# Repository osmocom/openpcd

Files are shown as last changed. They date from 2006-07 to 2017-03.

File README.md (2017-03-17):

OpenPCD, OpenPICC and SIMtrace device firmware
==============================================

This repository contains the C-language firmware of a couple of
different USB devices that share nothing in common but the fact that
they contain and Atmel AT91SAM7S microcontroller and that Harald Welte
was involved in their development.

The OpenPCD 1.x and OpenPICC 1.x devices are pretty much obsolete these
days, so SAM7S based SIMtrace 1.x is the only relevant platform these
days.

[Osmocom](https://osmocom.org/)
[SIMtrace](https://osmocom.org/projects/simtrace) is a USB-attached
peripheral device that is primarily used to sniff the traffic between a
SIM/USIM card and a Phone or cellular modem.

Homepage
--------

The official homepage of the project is
<https://osmocom.org/projects/simtrace/wiki/>

GIT Repository
--------------

You can clone from the official openpcd.git repository using

	git clone git://git.osmocom.org/openpcd.git

There is a cgit interface at <http://git.osmocom.org/openpcd/>

Documentation
-------------

Ther homepage (see above) contains a wiki with information as well as
the SIMtrace user manual.

Mailing List
------------

Discussions related to SIMtrace are happening on the
simtrace@lists.osmocom.org mailing list, please see
<https://lists.osmocom.org/mailman/listinfo/simtrace> for subscription
options and the list archive.

Please observe the [Osmocom Mailing List
Rules](https://osmocom.org/projects/cellular-infrastructure/wiki/Mailing_List_Rules)
when posting.

Contributing
------------

Our coding standards are described at
<https://osmocom.org/projects/cellular-infrastructure/wiki/Coding_standards>

We use accept code/patch submissions via e-mail to the above-mentioned
mailing list.

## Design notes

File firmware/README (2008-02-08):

Different Targets can be built by implementing a _init_func() and _main_func()_
function in src/main_foo.c

The resulting binary main_foo.bin can be built by issuing
	make BOARD=PCD TARGET=main_foo

If you want to add debugging support (debug unit aka DBGU, RS232), add DEBUG=1

Building dfu.bin (the DFU loader binary):
	make -f Makefile.dfu BOARD=PCD

For more information, please read http://wiki.openpcd.org/wiki/Firmware

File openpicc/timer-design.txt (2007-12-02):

from analog: SSC_DATA, CARRIER (via PLL)
to analog: MOD

MOD                   on PA17 (SSC TD, out), PA23 (PWM0, out)
SSC_DATA              on PA18 (SSC RD, in),  PA27 (TIOB2, in)
FRAME                 on PA20 (SSC RF, in)

CARRIER          (T5) on PA28 (TCLK1, in)
CARRIER_DIV_HELP (T3) on PA0  (TIOA0, out),  PA29 (TCLK2, in)
(TF)                  on PA26 (TIOA2, out),  PA15 (SSC TF, in)

SSC_CLOCK        (T4) on PA1  (TIOB0, out),  PA19 (SSC RK, in)

MOD: pure output, to modulation circuitry
	* either fed from SSC transmitter
	* or fed from PWM
SSC_DATA: pure input, from demulation circuitry
	* goes to SSC receiver
	* goes to tc_fdt as external event (TIOB2)
FRAME: set on any edge in SSC_DATA, reset by SSC_DATA_CONTROL (out)
	* goes to SSC receiver as frame signal

CARRIER: pure input, from PLL
	* goes to tc_cdiv and tc_fdt as XC1 (TCLK1)
CARRIER_DIV_HELP: internal signal, does ???
	* comes from tc_cdiv (TIOA0)
	* goes to tc_cdiv as XC2 (TCLK2)
TF: internal signal, transmission start
	* comes from tc_fdt (TIOA2)
	* goes to SSC transmitter as frame signal

SSC_CLOCK: internal signal, transceiver clock
	* comes from tc_cdiv (TIOB0)
	* goes to SSC transmitter and receiver as clock signal

tc_cdiv: XC1=TCLK1 (in), TIOB0 (out), TIOA0 (out), XC2=TCLK2 (in)
	TC0 enabled
	XC1 = TCLK1, XC2 = TCLK2
	TC0: Clock from XC1, Wave mode, WAVSEL=2 (up auto)
		TIOA0: RA compare = set, RC compare = clear, swtrg = clear
		TIOB0: eevent = set, RB compare = clear, swtrg = clear
		eevent: XC2, external trigger on rising edge
		RA = 1, RB = 1 + divider/2, RC = divider
	
	i.o.w: when CV = 0 (either through swtrg or through RC compare) then TIOA0 and TIOB0 are clear
		TIOA0 is set on RA compare (at CV=1+phase), is connected to XC2 (through TCLK2) and therefore triggers the external event which sets TIOB0
		TIOB0 is cleared at RB compare (at CV=1+divider/2+phase)
	that means: Compare A sets TIOB and Compare B clears TIOB, Compare C is fixed at the divisor value, Compare A and B are divisor/2 apart, yielding an exact 50% duty cycle with a variable phase shift (offset from CV=0)
	this trick is necessary because TIO{A,B} can't be directly affected by Compare {B,A}, so when using only one TIO you can either get a fixed duty cycle with zero offset compared to CV=0, or a variable offset yielding a variable duty cycle

tc_fdt: TIOA2 (out), TIOB2 (in), XC1=TCLK1 (in)
	TC2 enabled
	TC2: Clock from XC1, Wave mode, WAVSEL=0 (up)
		TIOA2: RA compare = set, RC compare = clear, eevent = clear
		TIOB2: eevent = nothing, RB compare = nothing
		eevent: TIOB2, external trigger on falling edge, clock started and enabled on external trigger
		clock stopped on RC compare
		RC = 0xffff, RB = frame_end_set, RA = fdt_set

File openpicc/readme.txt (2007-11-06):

OpenBeaconUSB firmware source code tree v0.1
--------------------------------------------

Copyright 2007 Milosch Meriac <milosch@openbeacon.de>
based on http://www.freertos.org/ embedded operating system

Visit http://www.openbeacon.org/ and http://wiki.openbeacon.org/ for further
informations.

All supplied code is licensed under GNU General Public License Version 2,
June 1991. See "license.txt" file for license informations. Alternative
license types are available for the "/application"-tree on request. Please
contact milosch@openbeacon.de on license issues.

The contained firmware source code is verified to compile flawless by using
GCC version 4.0.2 configured as ARM cross compiler.

The USB device creates a virtual serial COM port - you can access it by using
115200 baud, 8 data bit, no parity and one stop bit. Under Linux just plug it
into your computer - a /dev/ttyACM? device will appear automagically.

We personally prefer the "cu" command line tool from uucp-Package to access
the created serial port easily under Linux based operating systems.

For Microsoft Windows you have to use the supplied .inf-file from the
"win32driver" directory - you can verify the assigned COM port by using the
control panel.

Use the contained "at91flash"-tool to udpate to contained firmware. The
supplied script depends on our modified sam7 tool:
http://www.openpcd.org/dl/sam7utils-0.1.0-bm.tar.bz2

Enjoy !

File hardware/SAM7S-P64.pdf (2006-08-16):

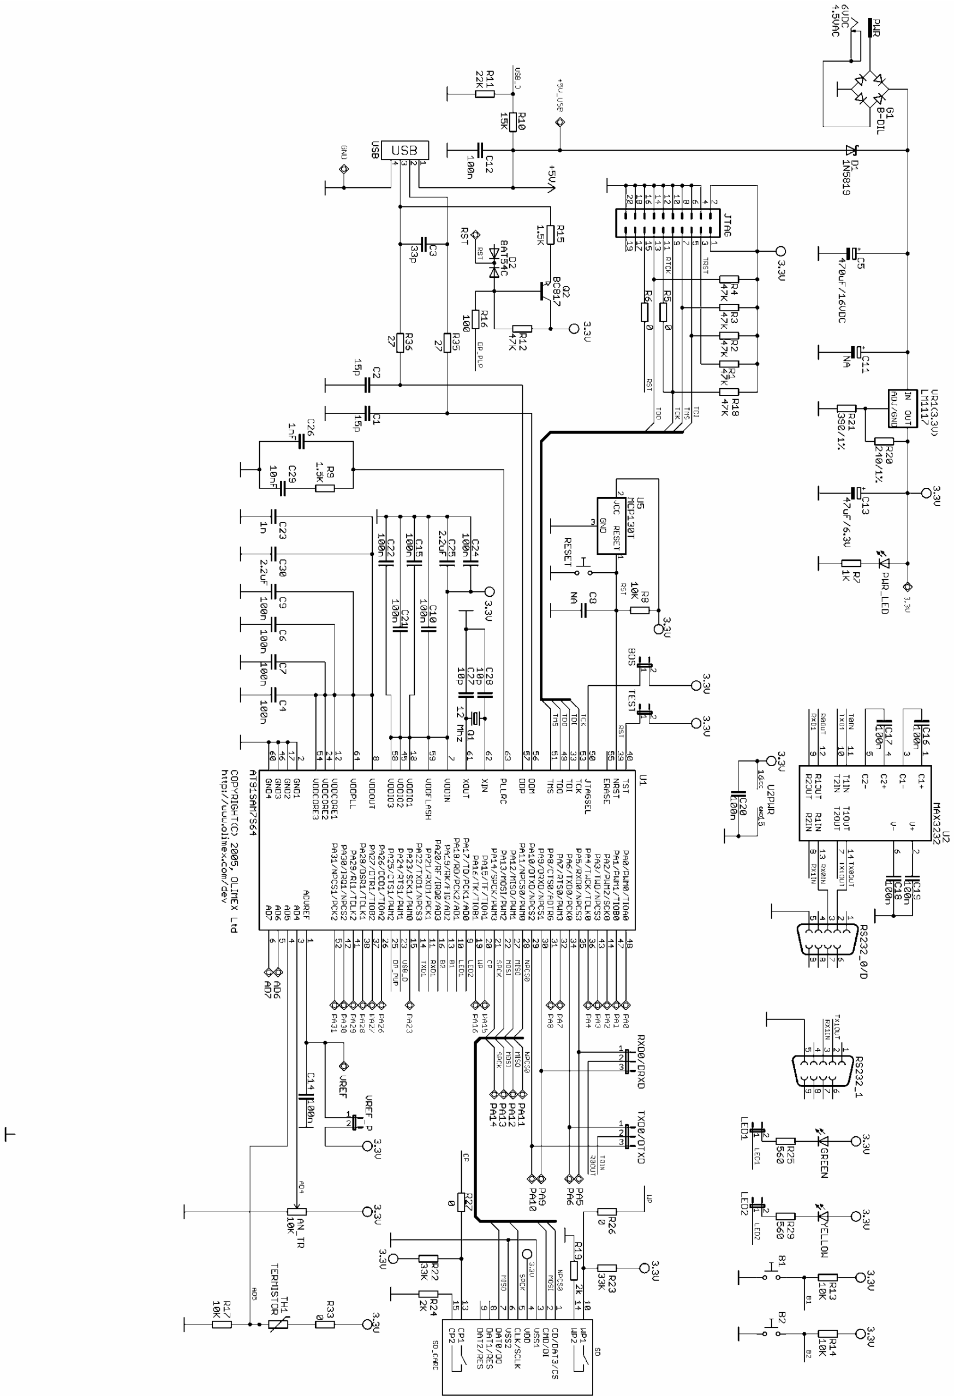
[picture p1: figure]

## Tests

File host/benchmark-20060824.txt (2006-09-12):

laforge@rama%pts/8 (1:27) kommerz/bitmanufaktur/openpcd/opcd_test > for f in 1 2 4 8 16 32 64 128 255; do ./opcd_test -u $f; done 
opcd_test - OpenPCD Test and Debug Program
(C) 2006 by Harald Welte <laforge@gnumonks.org>

starting DATA IN performance test (1 frames of 64 bytes)
TX: (4):  f1 00 ff 01
255 transfers (total 16320 bytes) in 508 miliseconds => 32125 bytes/sec
opcd_test - OpenPCD Test and Debug Program
(C) 2006 by Harald Welte <laforge@gnumonks.org>

starting DATA IN performance test (2 frames of 64 bytes)
TX: (4):  f1 00 ff 02
255 transfers (total 32640 bytes) in 510 miliseconds => 64000 bytes/sec
opcd_test - OpenPCD Test and Debug Program
(C) 2006 by Harald Welte <laforge@gnumonks.org>

starting DATA IN performance test (4 frames of 64 bytes)
TX: (4):  f1 00 ff 04
255 transfers (total 65280 bytes) in 508 miliseconds => 128503 bytes/sec
opcd_test - OpenPCD Test and Debug Program
(C) 2006 by Harald Welte <laforge@gnumonks.org>

starting DATA IN performance test (8 frames of 64 bytes)
TX: (4):  f1 00 ff 08
255 transfers (total 130560 bytes) in 510 miliseconds => 256000 bytes/sec
opcd_test - OpenPCD Test and Debug Program
(C) 2006 by Harald Welte <laforge@gnumonks.org>

starting DATA IN performance test (16 frames of 64 bytes)
TX: (4):  f1 00 ff 10
255 transfers (total 261120 bytes) in 764 miliseconds => 341780 bytes/sec
opcd_test - OpenPCD Test and Debug Program
(C) 2006 by Harald Welte <laforge@gnumonks.org>

starting DATA IN performance test (32 frames of 64 bytes)
TX: (4):  f1 00 ff 20
255 transfers (total 522240 bytes) in 1018 miliseconds => 513005 bytes/sec
opcd_test - OpenPCD Test and Debug Program
(C) 2006 by Harald Welte <laforge@gnumonks.org>

starting DATA IN performance test (64 frames of 64 bytes)
TX: (4):  f1 00 ff 40
255 transfers (total 1044480 bytes) in 2038 miliseconds => 512502 bytes/sec
opcd_test - OpenPCD Test and Debug Program
(C) 2006 by Harald Welte <laforge@gnumonks.org>

starting DATA IN performance test (128 frames of 64 bytes)
TX: (4):  f1 00 ff 80
255 transfers (total 2088960 bytes) in 3568 miliseconds => 585470 bytes/sec
opcd_test - OpenPCD Test and Debug Program
(C) 2006 by Harald Welte <laforge@gnumonks.org>

starting DATA IN performance test (255 frames of 64 bytes)
TX: (4):  f1 00 ff ff
255 transfers (total 4161600 bytes) in 6119 miliseconds => 680111 bytes/sec

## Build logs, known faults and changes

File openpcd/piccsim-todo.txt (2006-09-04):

- code to control digital potentiometers via SPI [MM]
	- chip select not SPI CS

- idea: use comparator to determine voltage range, then reconfigure amplifier
	- later

- problem: capacitance of digital poti
	- idea 1: 
	- idea 2: logarithmic amplifier using transistor

- ADC driver
	- core [MM]
		- trigger function (we want to read all values ASAP)
		- callback function (once new values are available)
		- init function (initialize ADC)
	- USB integration [HW]
		- simple READ_ADC command
		- one reply packet with all ADC channels

- OS timer 
	- how often?

- 'load modulation' driver
	- set PA2/PA3 to binary 0..3 

- add IO definitions for
	- PLL INHIBIT			low
	- SPI_SS1_GAIN		
	- SPI_SS2_DATA_THRESHOLD
	- BOOTLDR

- sampled data continuous output into file / stdout
	- trigger sampling by raising/falling edge (configurable)
	- sample only one buffer

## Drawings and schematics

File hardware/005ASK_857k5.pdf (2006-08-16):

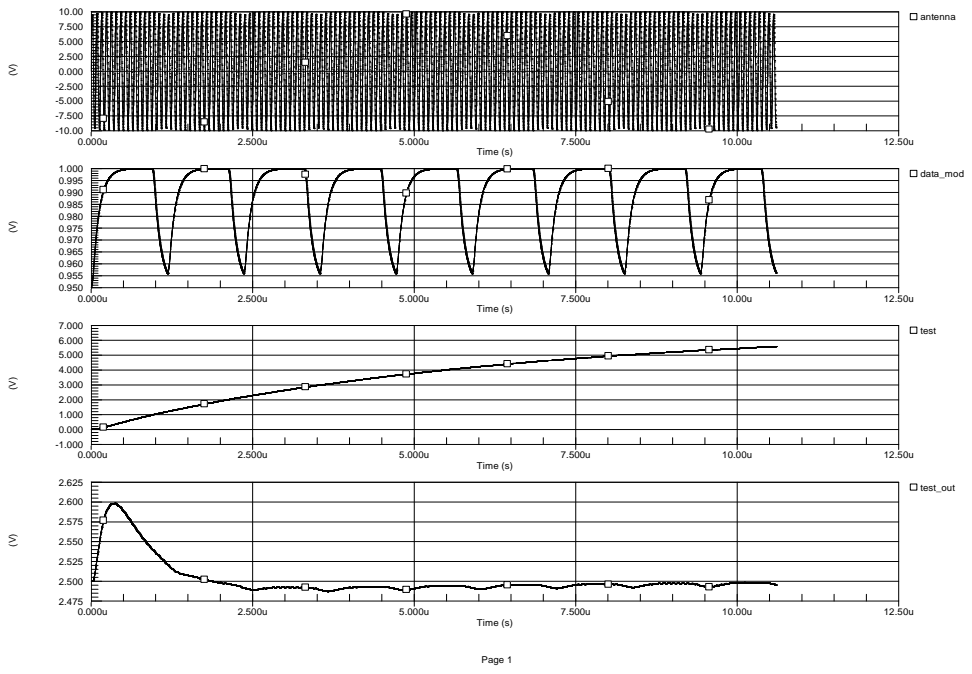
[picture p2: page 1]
Page 1; Time (s); antenna; data_mod; test; test_out

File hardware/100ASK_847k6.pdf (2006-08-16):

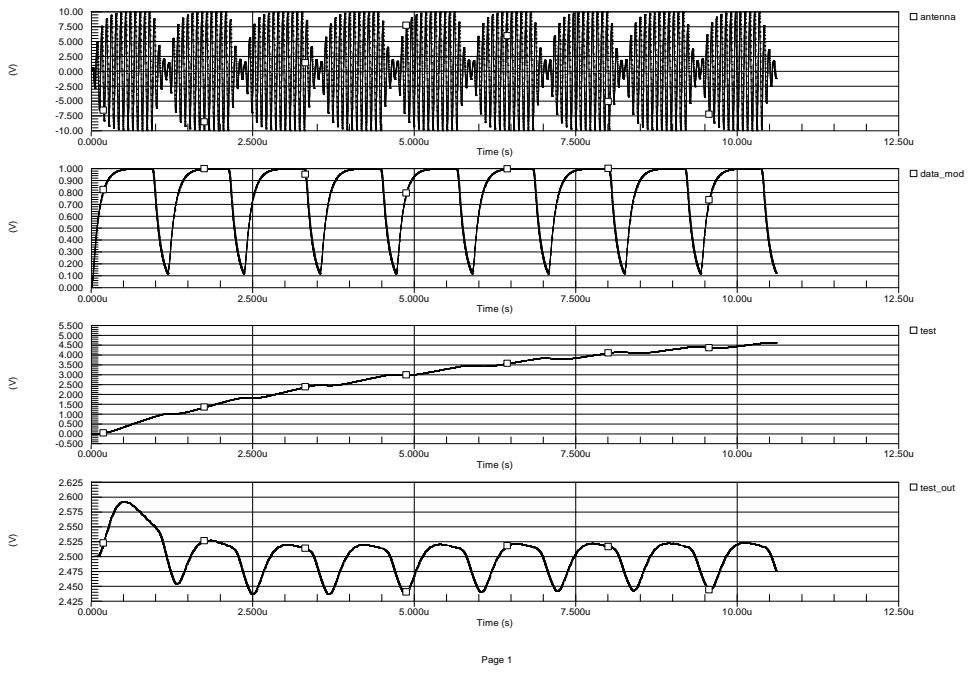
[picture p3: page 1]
Page 1; Time (s); antenna; data_mod; test; test_out

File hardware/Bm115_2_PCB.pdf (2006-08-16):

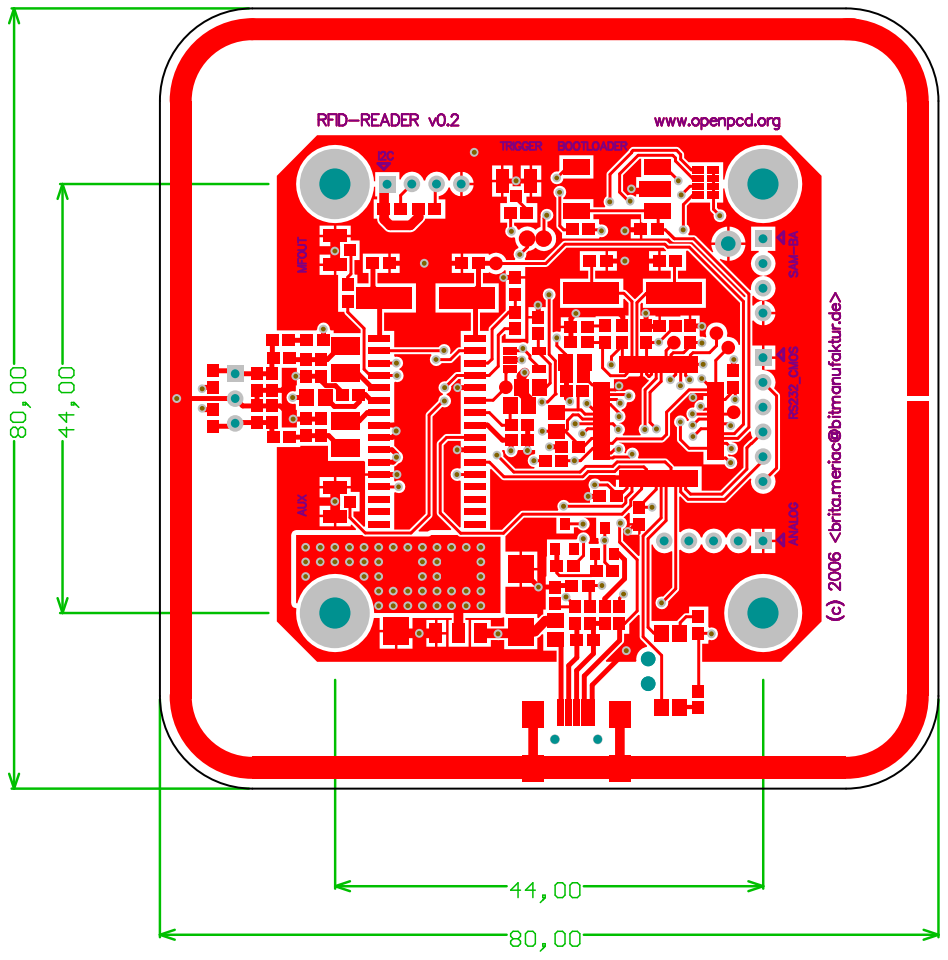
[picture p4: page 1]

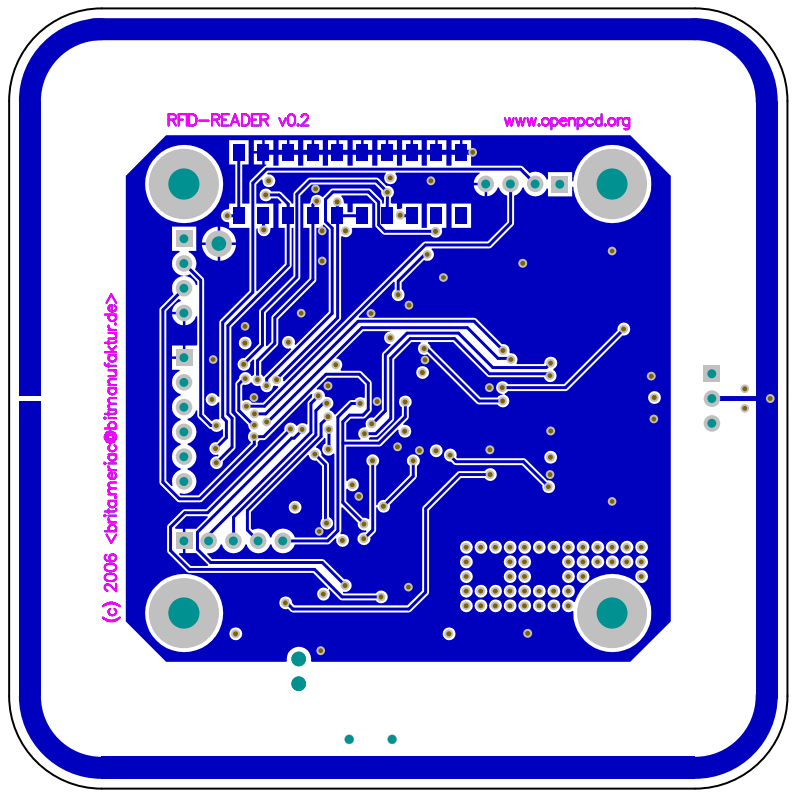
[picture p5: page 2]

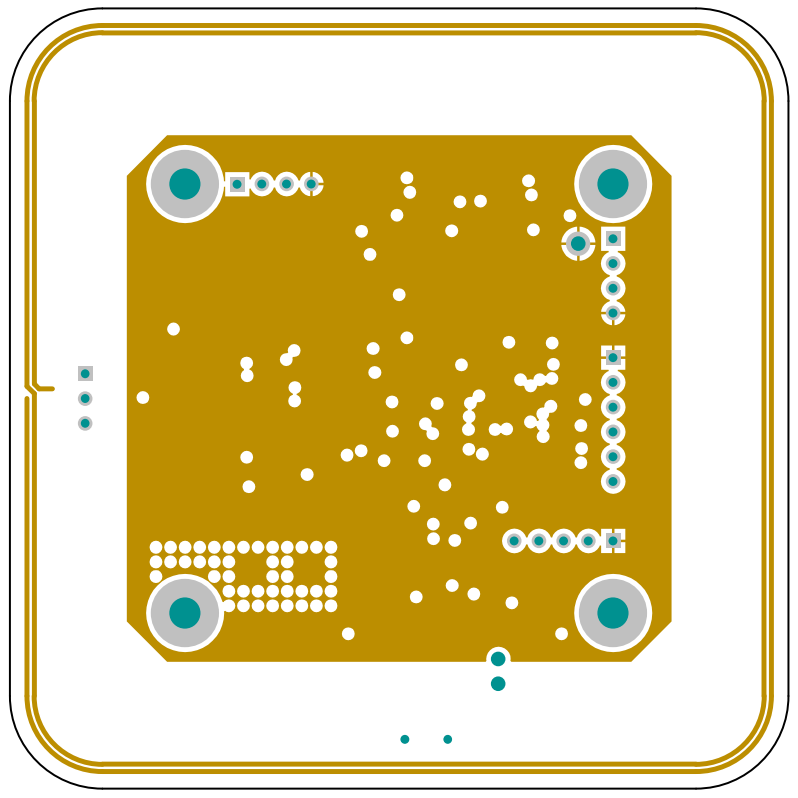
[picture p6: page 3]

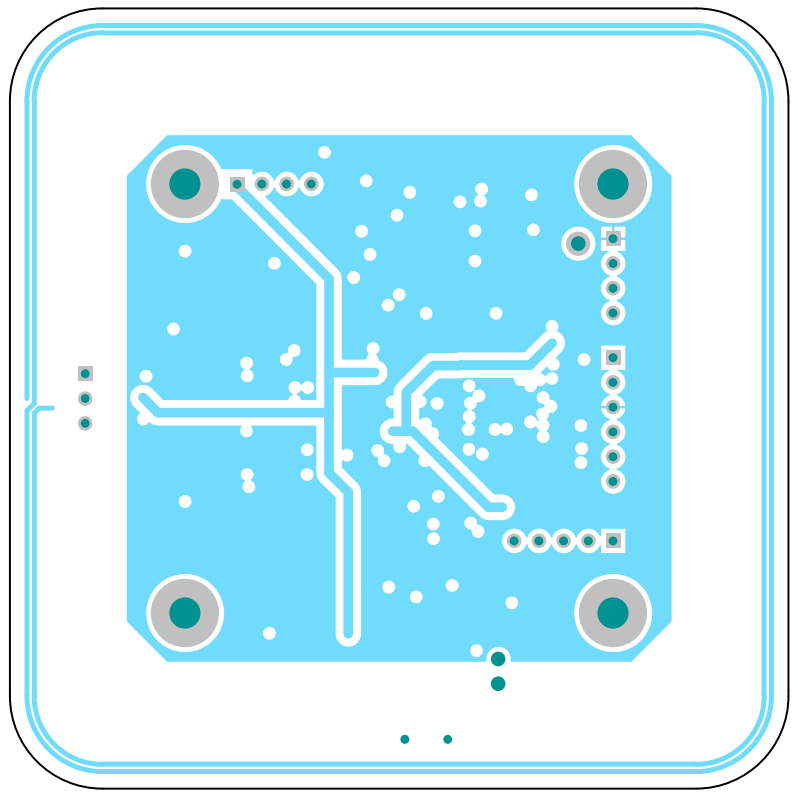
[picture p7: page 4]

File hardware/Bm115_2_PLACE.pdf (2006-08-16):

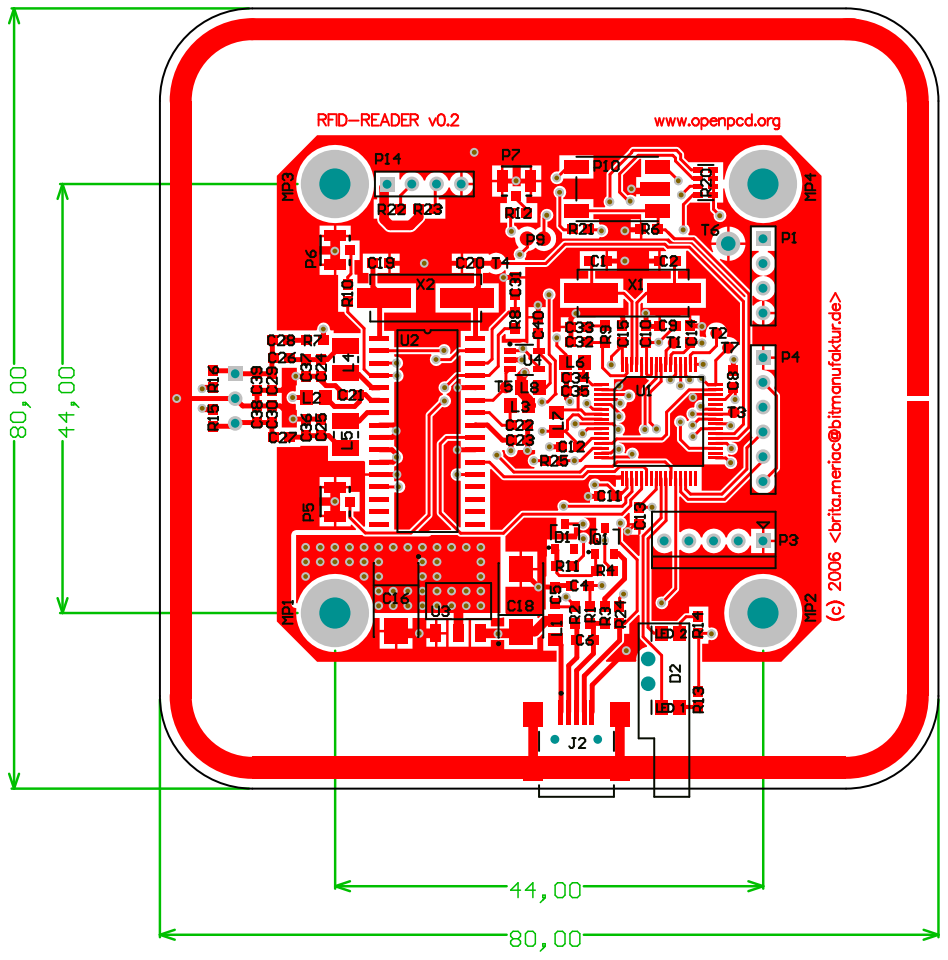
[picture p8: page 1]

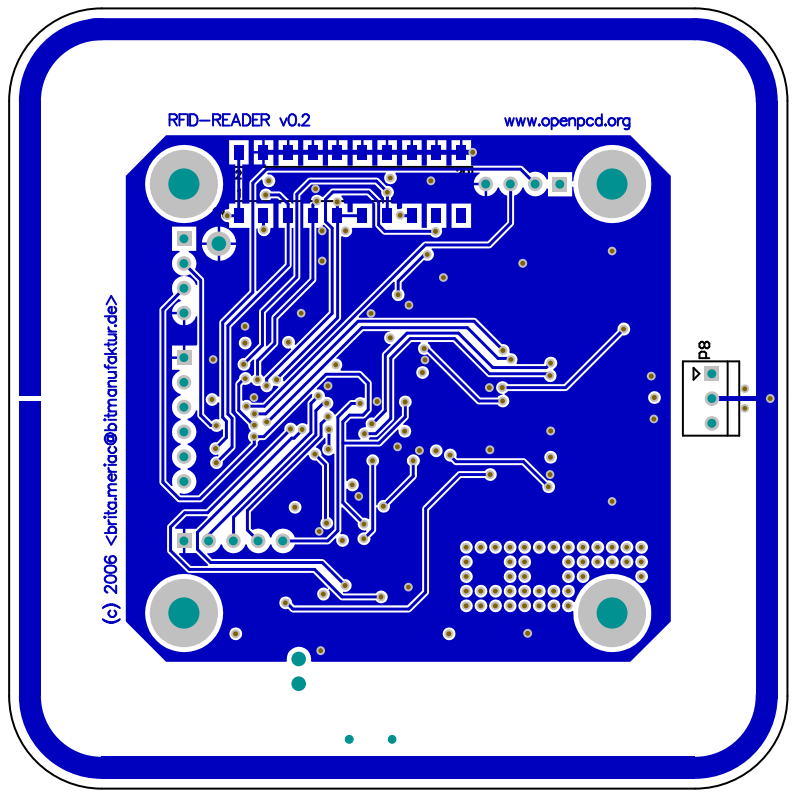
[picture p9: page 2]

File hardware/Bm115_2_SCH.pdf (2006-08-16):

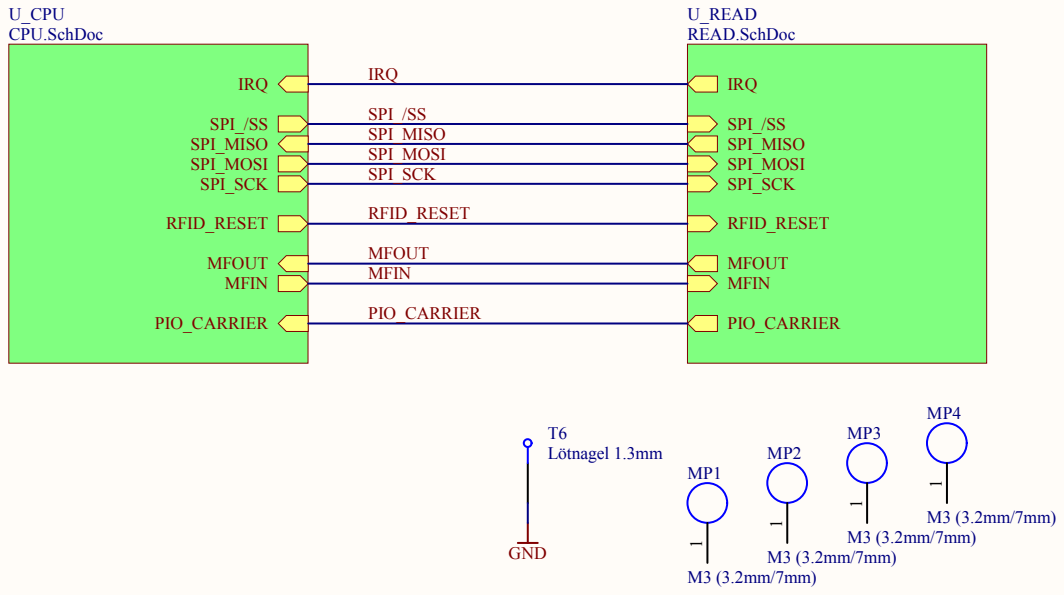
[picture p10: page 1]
Date:; Sheet of File:; H:\Projekte\..\TOP.SchDoc; Drawn By; 1 - TOP; T6Lötnagel 1.3m

Title
Testboard RFID Reader

http://www.bitmanufaktur.de

Dipl.-Ing. Brita Meriac

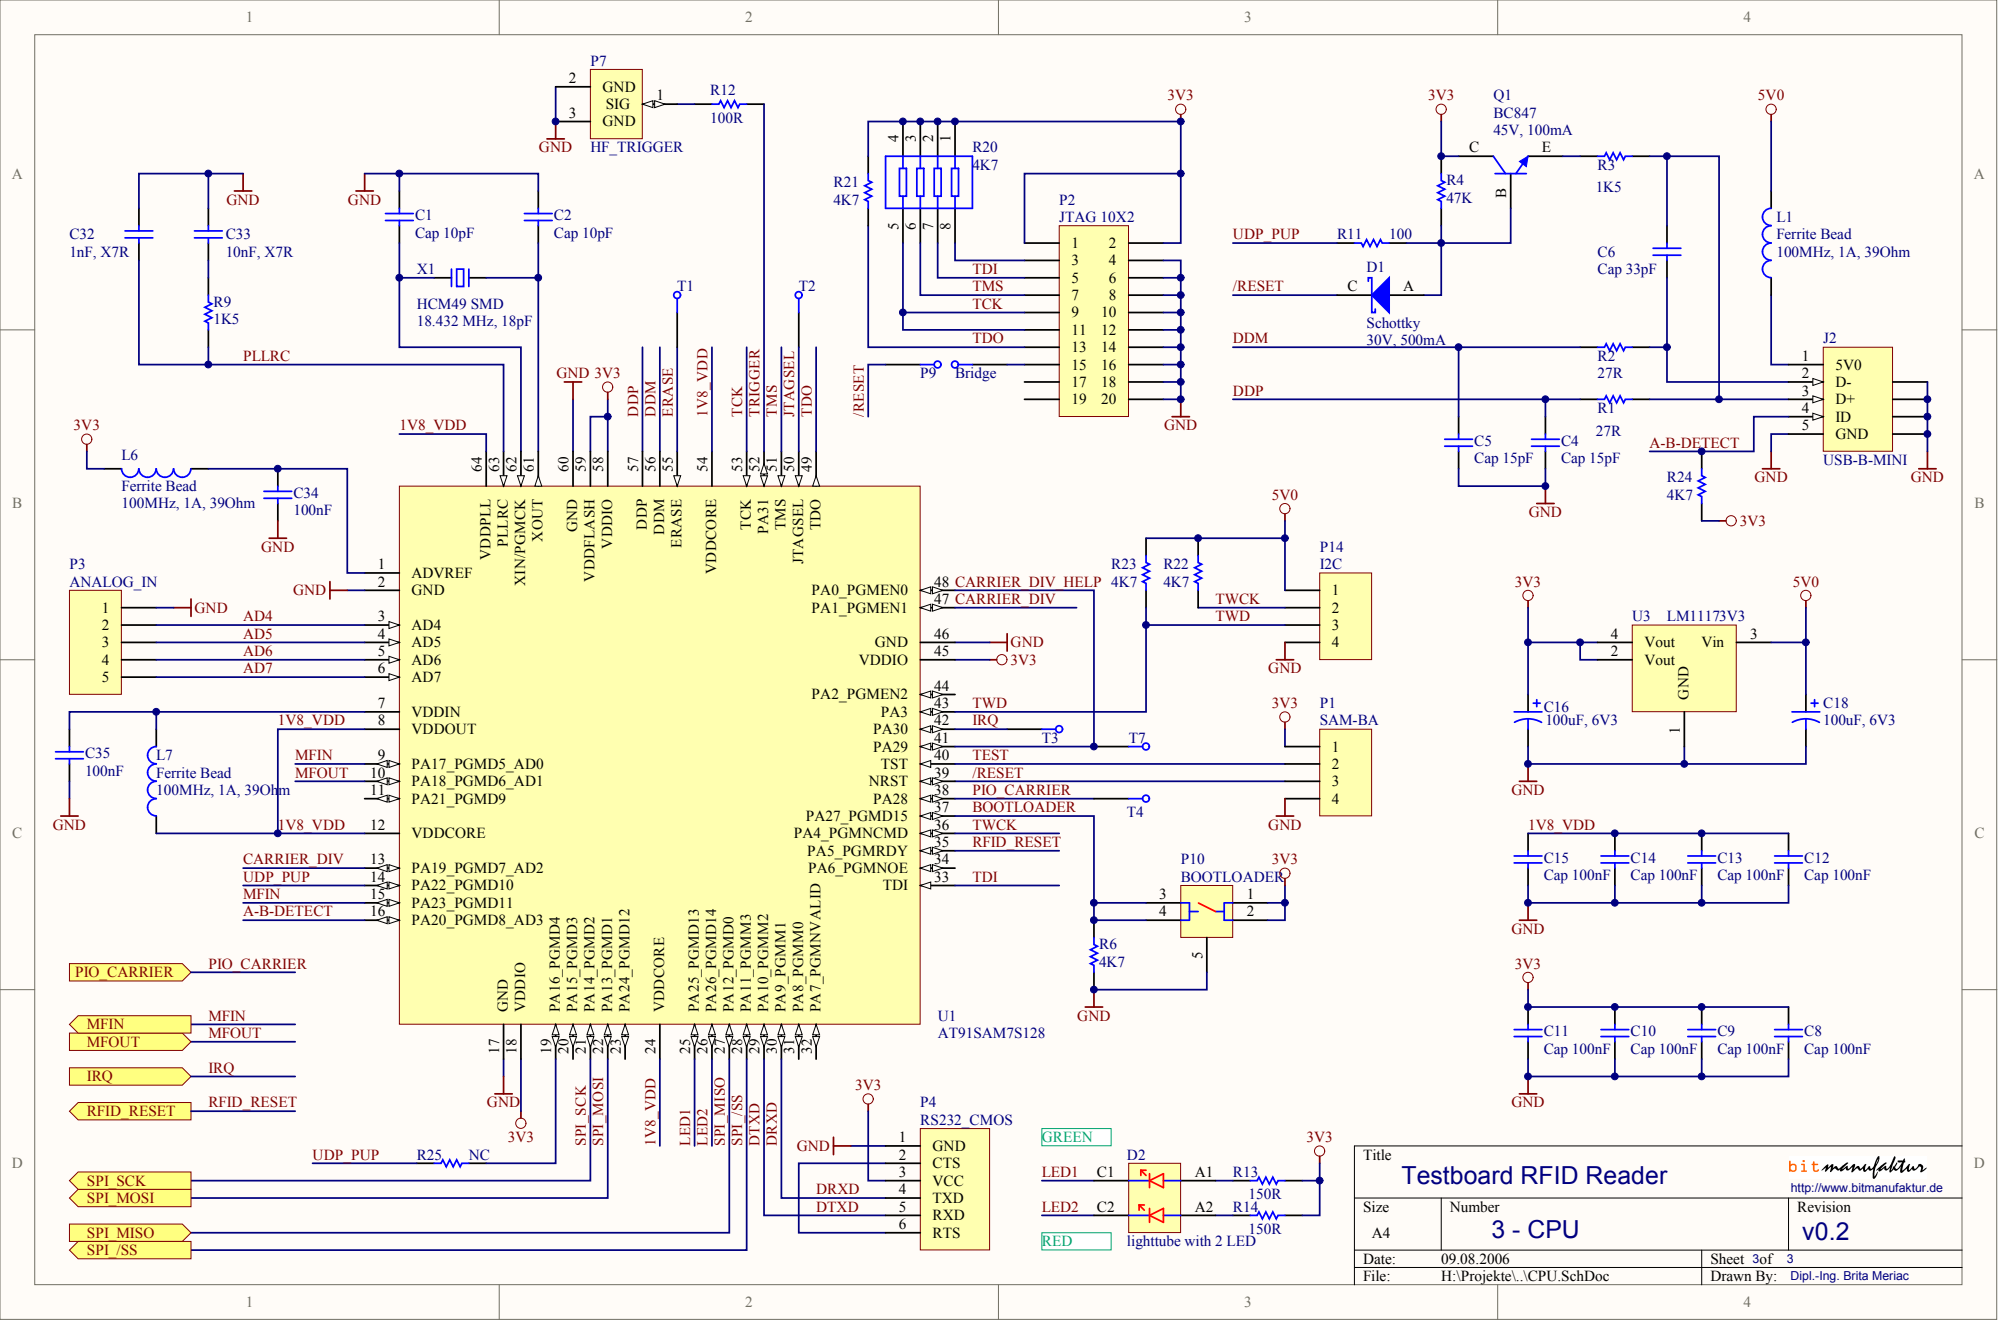
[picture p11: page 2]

XOUT 61 XIN/PGMCK 62 PLLRC 63 VDDPLL 64

http://www.bitmanufaktur.de

DTXD N0DTXD | 5

Dipl.-Ing. Brita Meriac

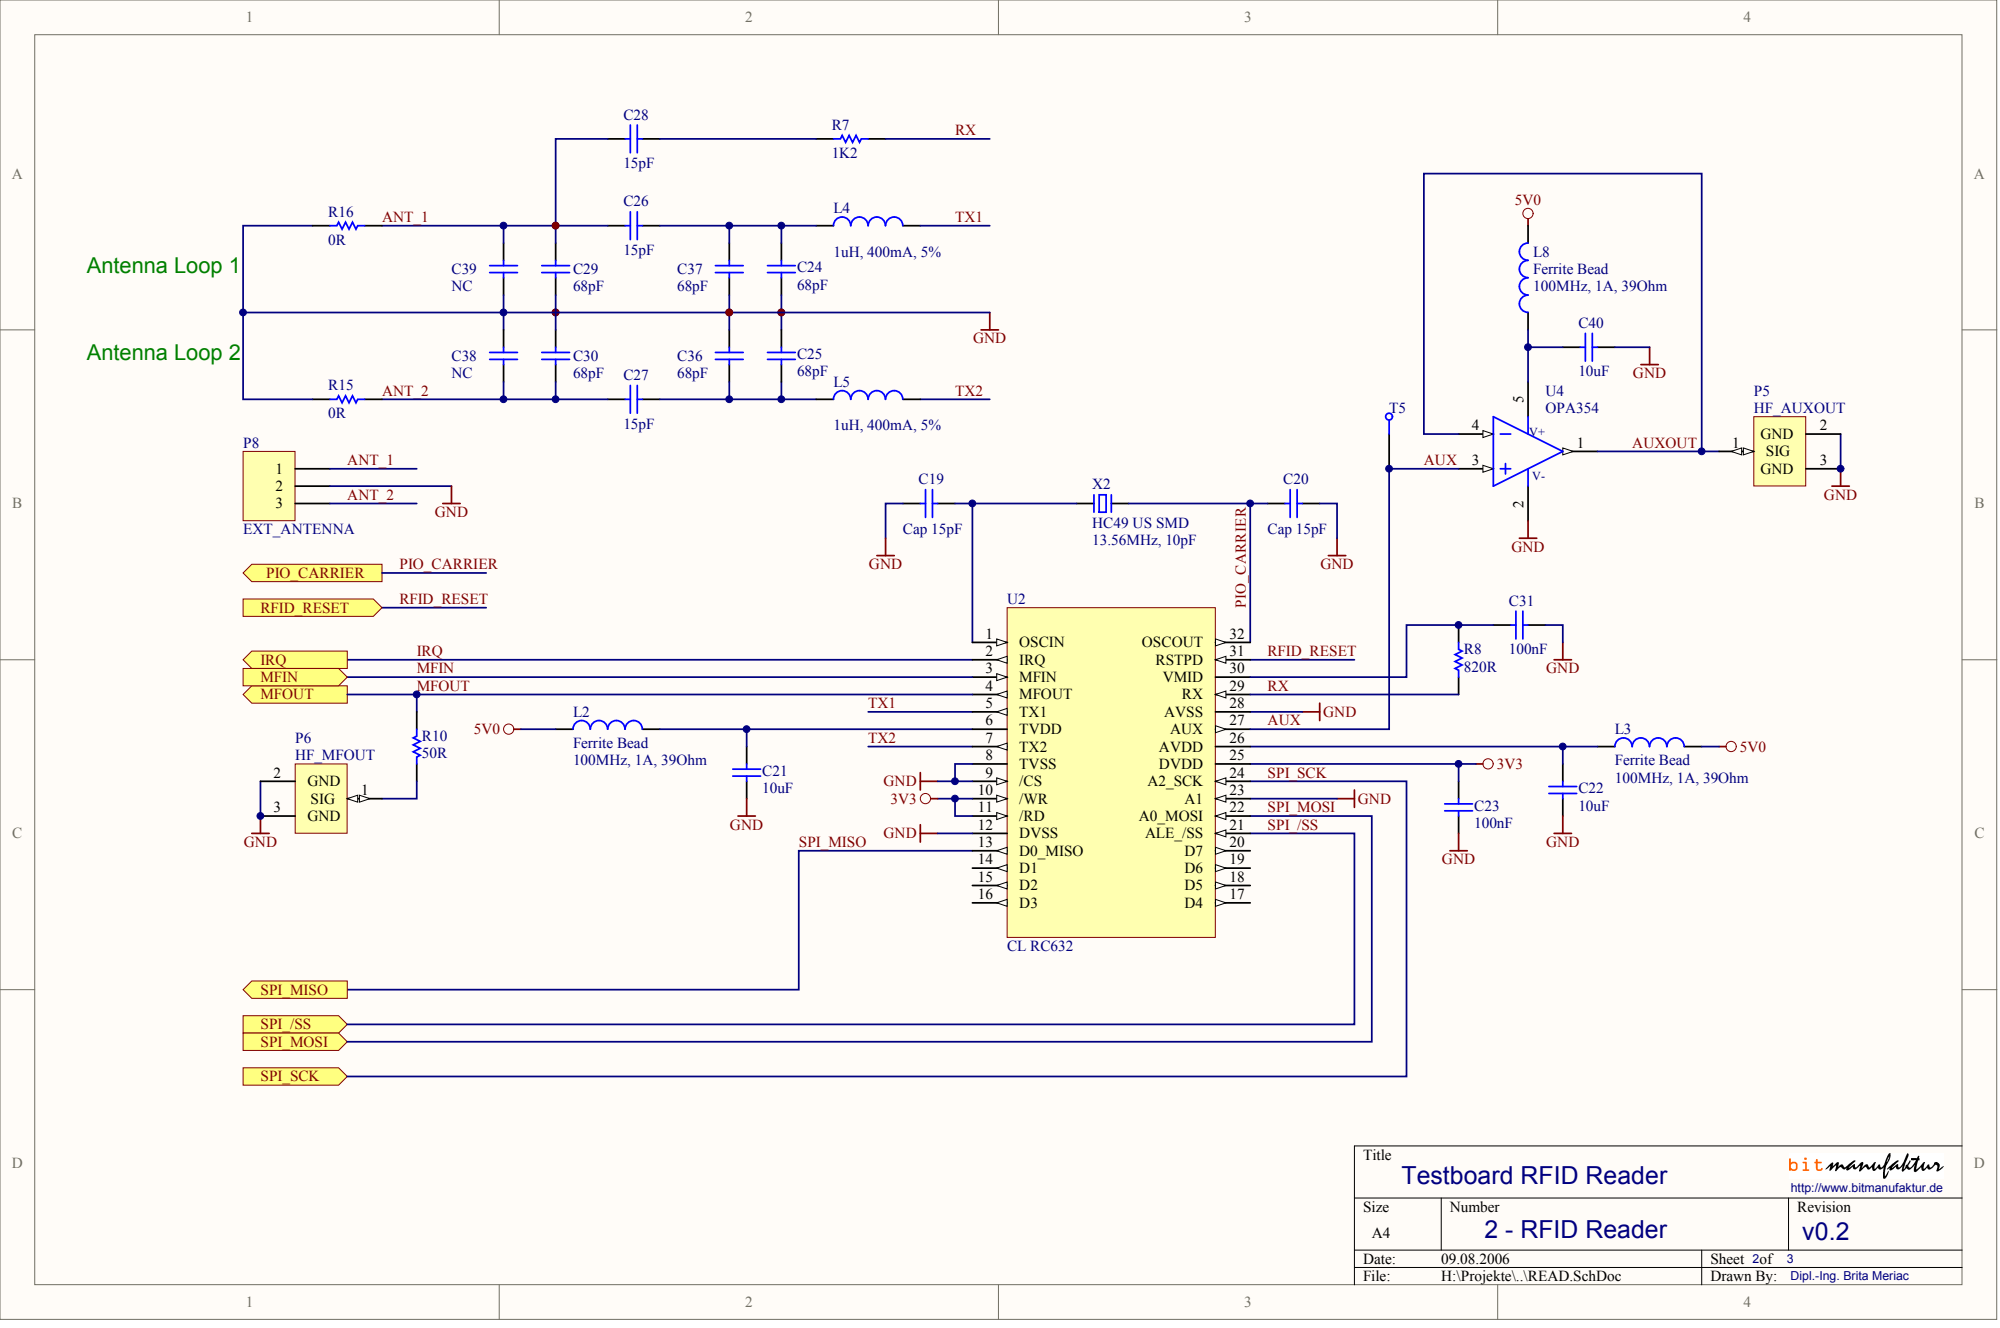
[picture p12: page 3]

RFID_RESET N0RFID0RESET | R8

MFOUT 4 P0U204 N0MFOUT P0U2029 P0U2029 P0U2029 P0U2029 | RX N0RX

TVDD 6 P0U2027 P0U2027 P0U2027 P0U2027 TX2 7 TVSS 8 | AUX

/RD 11 | SPI_MOSI
DVSS 12 P0U2021 P0U2021 P0U2021 P0U2021 | SPI_/SS N0SPI0/SS

SPI_MISO | D0_MISO 13 P0U2013 N0SPI0MISO P0U2020 P0U2020 P0U2020 P0U2020 P0U2013 P0U2013 P0U2013

D1 14 P0U2019 P0U2019 P0U2019 P0U2019
D2 15 P0U2018 P0U2018 P0U2018 P0U2018

http://www.bitmanufaktur.de

Dipl.-Ing. Brita Meriac

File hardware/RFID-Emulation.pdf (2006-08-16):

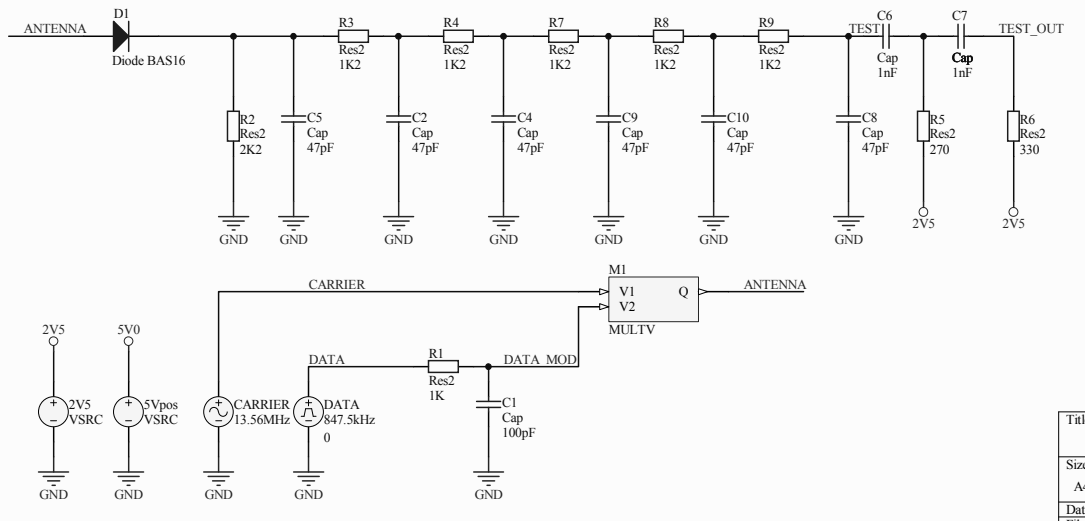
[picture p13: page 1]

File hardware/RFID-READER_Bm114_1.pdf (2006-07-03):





Date:; Sheet of File:; H:\Projekte\..\TOP.SchDoc; Drawn By; 1 - TOP

Title
Testboard RFID Reader

http://www.bitmanufaktur.de

Dipl.-Ing. Brita Meriac


18.432 MHz, 18pF 1V8_VDD N01V80VDD N01V80VDD

XOUT 61 XIN/PGMCK 62 PLLRC 63 VDDPLL 64

1V8_VDD N01V80VDD | 8

MF IN N0MFIN MFOUT N0MFOUT N0PA21 1V8_VDD N01V80VDD | 9 | PA18_PGMD6_AD1 10 PA21_PGMD9 11 P0U1011 N0PA21

DTXD N0DTXD N0DTXD
DRXD N0DRXD N0DRXD | P0P402 P0P402

http://www.bitmanufaktur.de

Dipl.-Ing. Brita Meriac


RFID_RESET N0RFID0RESET | R8

MFOUT 4 P0U204 N0MFOUT P0U2029 P0U2029 P0U2029 P0U2029 | RX N0RX

TX1 5 P0U2028 P0U2028 P0U2028 P0U2028 TVDD 6 TX2 7 TVSS 8 /CS 9

P0U2010 P0U2010 | /WR 10
/RD 11 | SPI_MOSI
DVSS 12 P0U2021 P0U2021 P0U2021 P0U2021 | SPI_/SS N0SPI0/SS

SPI_MISO | D0_MISO 13 P0U2013 N0SPI0MISO P0U2020 P0U2020 P0U2020 P0U2020 P0U2013 P0U2013 P0U2013

D1 14 P0U2019 P0U2019 P0U2019 P0U2019
D2 15 P0U2018 P0U2018 P0U2018 P0U2018

http://www.bitmanufaktur.de

Dipl.-Ing. Brita Meriac

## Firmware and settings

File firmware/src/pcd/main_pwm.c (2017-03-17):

/* main_pwm - OpenPCD firmware for generating a PWM-modulated 13.56MHz
 *	      carrier
 *
 * To use this, you need to connect PIOA P0 with MFIN of the reader.
 *
 * (C) 2006 by Harald Welte <hwelte@hmw-consulting.de>
 *
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
 */

#include <errno.h>
#include <string.h>
#include <lib_AT91SAM7.h>
#include "../openpcd.h"
#include <pcd/rc632.h>
#include <os/dbgu.h>
#include <os/led.h>
#include <os/pwm.h>
#include <os/tc_cdiv.h>
#include <os/pcd_enumerate.h>
#include <os/usb_handler.h>

#ifdef SSC
#include <pcd/ssc.h>
#endif

#define RAH NULL

static uint8_t force_100ask = 1;
static uint8_t mod_conductance = 0x3f;
static uint8_t cw_conductance = 0x3f;
static uint16_t duty_percent = 22;

#define ARRAY_SIZE(x) (sizeof(x) / sizeof((x)[0]))
static uint32_t pwm_freq[] = { 105937, 211875, 423750, 847500 };
static uint8_t pwm_freq_idx = 0;

static void rc632_modulate_mfin()
{
	opcd_rc632_reg_write(RAH, RC632_REG_TX_CONTROL, 
			RC632_TXCTRL_MOD_SRC_MFIN|RC632_TXCTRL_TX2_INV|
			RC632_TXCTRL_TX1_RF_EN|RC632_TXCTRL_TX2_RF_EN);
}

/* (77/40) ^ EXPcsCfgCW */
/* 1, 1.925, 3.705625, 7.13332812 */

#define COND_MANT(x)	(x & 0x0f)
#define COND_EXP(x)	((x & 0x30) >> 4)

static const uint16_t rsrel_expfact[] = { 1000, 1925, 3706, 7133 };

static uint32_t calc_conduct_rel(uint8_t inp)
{
	uint32_t cond_rel;

	cond_rel = COND_MANT(inp) * rsrel_expfact[COND_EXP(inp)];
	cond_rel = cond_rel / 1000;

	return cond_rel;
}

static const uint8_t rsrel_table[] = {
	0, 16, 32, 48, 1, 17, 2, 3, 33, 18, 4, 5, 19, 6, 7, 49, 34, 20,
	8, 9, 21, 10, 11, 35, 22, 12, 13, 23, 14, 50, 36, 15, 24, 25,
	37, 26, 27, 51, 38, 28, 29, 39, 30, 52, 31, 40, 41, 53, 42, 43,
	54, 44, 45, 55, 46, 47, 56, 57, 58, 59, 60, 61, 62, 63 };


static const uint16_t cdivs[] = { 128, 64, 32, 16 };
static int cdiv_idx = 0;

static void help(void)
{
	DEBUGPCR("o: decrease duty     p: increase duty\r\n"
		 "k: stop pwm          l: start pwn\r\n"
		 "n: decrease freq     m: incresae freq\r\n"
		 "v: decrease mod_cond b: increase mod_cond\r\n"
		 "g: decrease cw_cond  h: increase cw_cond");
	DEBUGPCR("u: PA23 const 1      y: PA23 const 0\r\n"
		 "t: PA23 PWM0         f: toggle Force100ASK\r\n"
		 "{: decrease cdiv_idx }: increse cdiv idx");
}

void _init_func(void)
{
	DEBUGPCR("\r\n===> main_pwm <===\r\n");
	help();

	rc632_init();
	DEBUGPCRF("turning on RF");
	rc632_turn_on_rf(RAH);

	/* switch PA17 (connected to MFIN on board) to input */
	AT91F_PIO_CfgInput(AT91C_BASE_PIOA, AT91C_PIO_PA17);

	DEBUGPCRF("Initializing carrier divider");
	tc_cdiv_init();

	DEBUGPCRF("Initializing PWM");
	pwm_init();
	pwm_freq_set(0, 105937);
	pwm_start(0);
	pwm_duty_set_percent(0, 22);	/* 22% of 9.43uS = 2.07uS */
	rc632_modulate_mfin();

#ifdef SSC
	DEBUGPCRF("Initializing SSC RX");
	ssc_rx_init();
#endif
}

int _main_dbgu(char key)
{
	switch (key) {
	case 'o':
		if (duty_percent >= 1)
			duty_percent--;
		pwm_duty_set_percent(0, duty_percent);
		break;
	case 'p':
		if (duty_percent <= 99)
			duty_percent++;
		pwm_duty_set_percent(0, duty_percent);
		break;
	case 'k':
		pwm_stop(0);
		break;
	case 'l':
		pwm_start(0);
		break;
	case 'n':
		if (pwm_freq_idx > 0) {
			pwm_freq_idx--;
			pwm_stop(0);
			pwm_freq_set(0, pwm_freq[pwm_freq_idx]);
			pwm_start(0);
			pwm_duty_set_percent(0, 22);	/* 22% of 9.43uS = 2.07uS */
		}
		break;
	case 'm':
		if (pwm_freq_idx < ARRAY_SIZE(pwm_freq)-1) {
			pwm_freq_idx++;
			pwm_stop(0);
			pwm_freq_set(0, pwm_freq[pwm_freq_idx]);
			pwm_start(0);
			pwm_duty_set_percent(0, 22);	/* 22% of 9.43uS = 2.07uS */
		}
		break;
	case 'u':
		DEBUGPCRF("PA23 output high");
		AT91F_PIO_CfgOutput(AT91C_BASE_PIOA, AT91C_PIO_PA23);
		AT91F_PIO_SetOutput(AT91C_BASE_PIOA, AT91C_PIO_PA23);
		break;
	case 'y':
		DEBUGPCRF("PA23 output low");
		AT91F_PIO_CfgOutput(AT91C_BASE_PIOA, AT91C_PIO_PA23);
		AT91F_PIO_ClearOutput(AT91C_BASE_PIOA, AT91C_PIO_PA23);
		return 0;
		break;
	case 't':
		DEBUGPCRF("PA23 PeriphA (PWM)");
		AT91F_PIO_CfgPeriph(AT91C_BASE_PIOA, 0, AT91C_PA23_PWM0);
		return 0;
		break;
	case 'f':
		DEBUGPCRF("%sabling Force100ASK", force_100ask ? "Dis":"En");
		if (force_100ask) {
			force_100ask = 0;
			opcd_rc632_clear_bits(RAH, RC632_REG_TX_CONTROL,
					      RC632_TXCTRL_FORCE_100_ASK);
		} else {
			force_100ask = 1;
			opcd_rc632_set_bits(RAH, RC632_REG_TX_CONTROL,
					    RC632_TXCTRL_FORCE_100_ASK);
		}
		return 0;
		break;
	case 'v':
		if (mod_conductance > 0) {
			mod_conductance--;
			opcd_rc632_reg_write(RAH, RC632_REG_MOD_CONDUCTANCE,
					     rsrel_table[mod_conductance]);
		}
		break;
	case 'b':
		if (mod_conductance < 0x3f) {
			mod_conductance++;
			opcd_rc632_reg_write(RAH, RC632_REG_MOD_CONDUCTANCE,
					     rsrel_table[mod_conductance]);
		}
		break;
	case 'g':
		if (cw_conductance > 0) {
			cw_conductance--;
			opcd_rc632_reg_write(RAH, RC632_REG_CW_CONDUCTANCE, 
					     rsrel_table[cw_conductance]);
		}
		break;
	case 'h':
		if (cw_conductance < 0x3f) {
			cw_conductance++;
			opcd_rc632_reg_write(RAH, RC632_REG_CW_CONDUCTANCE, 
					     rsrel_table[cw_conductance]);
		}
		break;
	case '?':
		help();
		return 0;
		break;
	case '<':
		tc_cdiv_phase_inc();
		break;
	case '>':
		tc_cdiv_phase_dec();
		break;
	case '{':
		if (cdiv_idx > 0)
			cdiv_idx--;
		tc_cdiv_set_divider(cdivs[cdiv_idx]);
		break;
	case '}':
		if (cdiv_idx < ARRAY_SIZE(cdivs)-1)
			cdiv_idx++;
		tc_cdiv_set_divider(cdivs[cdiv_idx]);
		break;
#ifdef SSC
	case 's':
		ssc_rx_start();
		break;
	case 'S':
		ssc_rx_stop();
		break;
#endif
	default:
		return -EINVAL;
	}

	DEBUGPCR("pwm_freq=%u, duty_percent=%u, mod_cond=%u, cw_cond=%u tc_cdiv=%u", 
		 pwm_freq[pwm_freq_idx], duty_percent, mod_conductance, cw_conductance,
		 cdivs[cdiv_idx]);
	
	return 0;
}


void _main_func(void)
{
	/* first we try to get rid of pending to-be-sent stuff */
	usb_out_process();

	/* next we deal with incoming requests from USB EP1 (OUT) */
	usb_in_process();

	/* try unthrottling sources since we now are [more] likely to
	 * have empty request contexts */
	rc632_unthrottle();
#ifdef SSC
	ssc_rx_unthrottle();
#endif

	led_toggle(2);
}

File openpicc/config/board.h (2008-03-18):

/***************************************************************
 *
 * OpenBeacon.org - board specific configuration
 *
 * Copyright 2007 Milosch Meriac <meriac@openbeacon.de>
 *
 * change this file to reflect hardware design changes
 *
 ***************************************************************

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
    You should have received a copy of the GNU General Public License along
    with this program; if not, write to the Free Software Foundation, Inc.,
    51 Franklin Street, Fifth Floor, Boston, MA 02110-1301 USA.

*/
#ifndef Board_h
#define Board_h

#include "lib_AT91SAM7.h"

#define RAMFUNC __attribute__ ((long_call, section (".ramfunc")))
#define IRQFUNC __attribute__ ((interrupt("IRQ")))
#define FIQFUNC __attribute__ ((interrupt("FIQ")))

#define true	-1
#define false	0

/*-------------------------------*/
/* SAM7Board Memories Definition */
/*-------------------------------*/

#define  ENVIRONMENT_SIZE	1024
#define  FLASH_PAGE_NB		AT91C_IFLASH_NB_OF_PAGES-(ENVIRONMENT_SIZE/AT91C_IFLASH_PAGE_SIZE)

/*-----------------*/
/* Master Clock    */
/*-----------------*/

#define EXT_OC		18432000	// Exetrnal ocilator MAINCK
#define MCK		47923200	// MCK (PLLRC div by 2)
#define MCKKHz		(MCK/1000)	//

/*-----------------*/
/* Board version   */
/*-----------------*/
enum openpicc_release {
	OPENPICC_v0_4,    /* Schematics v0.4, as sold in the shop */
	
	OPENPICC_v0_4_p1, /* based on schematics v0.4; Modifications: 
	 				   * + PLL_LOCK relocated from PA4 to PA5
	 				   * + Copy of FRAME routed to PA4 
	 				   * + Connection between R18 and 3V3 removed, instead R18 is now connected to PA31*/
	OPENPICC_v0_4_p2, /* Enhancement of v0.4p1, Add:
					   * + CARRIER can be switched from PLL output to original carrier
					   *   using PA30
					   */
	OPENPICC_v0_4_karsten, /* Combination of p1 and p2:
							* + Has everything v0.4p1 has
							* + CARRIER is fixed to original carrier, PLL ist completely out of the loop*/
};
enum clock_source { 
	CLOCK_SELECT_PLL,
	CLOCK_SELECT_CARRIER,
};

struct openpicc_hardware {
	enum openpicc_release release;
	char *release_name;
	struct {
		int data_gating:1;
		int clock_gating:1;
		int clock_switching:1;
	} features;
	enum clock_source default_clock;
	
	int PLL_LOCK;
	
	int CLOCK_GATE;
	int DATA_GATE;
	int CLOCK_SWITCH;
};

extern const struct openpicc_hardware OPENPICC_HARDWARE[];
extern const struct openpicc_hardware *OPENPICC;

/*-----------------*/
/* Pins            */
/*-----------------*/

#define LED_GREEN	AT91C_PIO_PA25
#define LED_RED		AT91C_PIO_PA12
#define LED_MASK	(LED_GREEN|LED_RED)

#define OPENPICC_PIO_SS2_DT_THRESH AT91C_PIO_PA8
#define OPENPICC_PIO_PLL_INHIBIT   AT91C_PIO_PA24

#define OPENPICC_MOD_PWM	   AT91C_PA23_PWM0
#define OPENPICC_MOD_SSC	   AT91C_PA17_TD
#define OPENPICC_SSC_DATA	   AT91C_PA18_RD
#define OPENPICC_SSC_CLOCK	   AT91C_PA19_RK
#define OPENPICC_SSC_TF		   AT91C_PIO_PA15

#define OPENPICC_PIO_FRAME         AT91C_PIO_PA20

#define OPENPICC_PIO_SSC_DATA_CONTROL   AT91C_PIO_PA21
#define OPENPICC_PIO_AB_DETECT          AT91C_PIO_PA22
#define OPENPICC_PIO_PLL_INHIBIT        AT91C_PIO_PA24

#define OPENPICC_ADC_FIELD_STRENGTH    AT91C_ADC_CH4

#define OPENPICC_PIO_LOAD1              AT91C_PIO_PA2
#define OPENPICC_PIO_LOAD2              AT91C_PIO_PA3

#define OPENPICC_PIO_CARRIER_IN          AT91C_PA28_TCLK1
#define OPENPICC_PIO_CARRIER_DIV_OUT     AT91C_PA1_TIOB0
#define OPENPICC_PIO_CDIV_HELP_OUT       AT91C_PA0_TIOA0
#define OPENPICC_PIO_CDIV_HELP_IN        AT91C_PA29_TCLK2

#define OPENPICC_IRQ_PRIO_PIO   (AT91C_AIC_PRIOR_LOWEST+4)
#define OPENPICC_IRQ_PRIO_SSC    (AT91C_AIC_PRIOR_HIGHEST-1)
#define OPENPCD_IRQ_PRIO_TC_FDT (AT91C_AIC_PRIOR_LOWEST+3)

/*-----------------*/
/* task priorities */
/*-----------------*/

#define TASK_BEACON_PRIORITY	( tskIDLE_PRIORITY )
#define TASK_BEACON_STACK	( 512 )

#define TASK_CMD_PRIORITY	( tskIDLE_PRIORITY + 2 )
#define TASK_CMD_STACK		( 512 )

#define TASK_USB_PRIORITY	( tskIDLE_PRIORITY + 2 )
#define TASK_USB_STACK		( 512 )

#define TASK_ISO_PRIORITY	( tskIDLE_PRIORITY + 3 )
#define TASK_ISO_STACK		( 512 )

#define TASK_NRF_PRIORITY	( tskIDLE_PRIORITY + 3 )
#define TASK_NRF_STACK		( 512 )

#endif /* Board_h */

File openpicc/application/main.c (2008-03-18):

/***************************************************************
 *
 * OpenBeacon.org - main entry for 2.4GHz RFID USB reader
 *
 * Copyright 2007 Milosch Meriac <meriac@openbeacon.de>
 *
 * basically starts the USB task, initializes all IO ports
 * and introduces idle application hook to handle the HF traffic
 * from the nRF24L01 chip
 *
 ***************************************************************

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
    You should have received a copy of the GNU General Public License along
    with this program; if not, write to the Free Software Foundation, Inc.,
    51 Franklin Street, Fifth Floor, Boston, MA 02110-1301 USA.

*/
/* Library includes. */
#include <string.h>
#include <stdio.h>

#include <FreeRTOS.h>
#include <AT91SAM7.h>
#include <lib_AT91SAM7.h>
#include <USB-CDC.h>
#include <task.h>

#include "openpicc.h"
#include "board.h"
#include "led.h"
#include "env.h"
#include "cmd.h"
#include "da.h"
#include "adc.h"
#include "pll.h"
#include "pio_irq.h"
#include "tc_cdiv.h"
#include "tc_cdiv_sync.h"
#include "tc_fdt.h"
#include "usb_print.h"
#include "iso14443_layer3a.h"
#include "iso14443_sniffer.h"
#include "iso14443a_pretender.h"
#include "decoder.h"
#include "tc_sniffer.h"
#include "performance.h"

static inline int detect_board(void)
{
	/* OpenPICC board detection logic.
	 * Interesting board differences: PA31 is open on OPENPICC_v0_4 and connected
	 * to PA18 on OPENPICC_v0_4_p1. PA18 is connected to U7 on both and might read
	 * differently depending on the state of U7 (primarily depending on U5 and the
	 * receive circuitry).
	 * Strategy: Enable Pullups, read PA31 and PA18, if both read low then U7 is
	 * switched through and this is an v0.4p1. If PA18 reads low and PA31 reads high
	 * then U7 is switched through and this is an v0.4. If both read high, then U7 is
	 * not switched through and it might be either board. In this case drive PA31 down
	 * and see whether PA18 follows down, then it's a v0.4p1 otherwise a v0.4.
	 */
	int result = -1;
	
	AT91PS_PIO pio = AT91C_BASE_PIOA;
	u_int32_t old_OSR = pio->PIO_OSR, 
		old_ODSR = pio->PIO_ODSR,
		old_PUSR = pio->PIO_PPUSR,
		old_PSR = pio->PIO_PSR;
	
	pio->PIO_ODR   = AT91C_PIO_PA18 | AT91C_PIO_PA31;
	pio->PIO_PER   = AT91C_PIO_PA18 | AT91C_PIO_PA31;
	pio->PIO_PPUER = AT91C_PIO_PA18 | AT91C_PIO_PA31;
	
	unsigned int pa18 = AT91F_PIO_IsInputSet(pio, AT91C_PIO_PA18),
		pa31 = AT91F_PIO_IsInputSet(pio, AT91C_PIO_PA31);
	if(!pa18 && !pa31) {
	    //vLedInit();
		//vLedHaltBlinking(1);
		result = OPENPICC_v0_4_karsten;
	} else if(!pa18 && pa31) {
	    vLedInit();
		vLedHaltBlinking(2);
		// Needs to be tested, should be v0.4
	} else if(pa18 && pa31) {
		// Can be either board
		pio->PIO_OER = AT91C_PIO_PA31;
		pio->PIO_CODR = AT91C_PIO_PA31;
		pa18 = AT91F_PIO_IsInputSet(pio, AT91C_PIO_PA18);
		if(!pa18) {
			result = OPENPICC_v0_4_karsten;
		} else {
		    vLedInit();
			vLedHaltBlinking(3);
			// Needs to be tested, should be v0.4
		}
		
		// Restore state
		if( old_OSR & AT91C_PIO_PA31 ) {
			pio->PIO_OER = AT91C_PIO_PA31;
			if(old_ODSR & AT91C_PIO_PA31) {
				pio->PIO_SODR = AT91C_PIO_PA31;
			} else {
				pio->PIO_CODR = AT91C_PIO_PA31;
			}
		} else {
			pio->PIO_ODR = AT91C_PIO_PA31;
		}
	}
	
	// Restore state
	if(old_PSR & AT91C_PIO_PA18) pio->PIO_PER = AT91C_PIO_PA18; else pio->PIO_PDR = AT91C_PIO_PA18;
	if(old_PSR & AT91C_PIO_PA31) pio->PIO_PER = AT91C_PIO_PA31; else pio->PIO_PDR = AT91C_PIO_PA31;
	
	if(old_PUSR & AT91C_PIO_PA18) pio->PIO_PPUDR = AT91C_PIO_PA18; else pio->PIO_PPUER = AT91C_PIO_PA18;
	if(old_PUSR & AT91C_PIO_PA31) pio->PIO_PPUDR = AT91C_PIO_PA31; else pio->PIO_PPUER = AT91C_PIO_PA31;
	
	return result;
}

/**********************************************************************/
static inline void prvSetupHardware (void)
{
	/* The very, very first thing we do is setup the global OPENPICC variable to point to
	 * the correct hardware information.
	 */
	int release = detect_board();
	if(release < 0) {
		vLedInit();
		vLedHaltBlinking(0);
	}
	OPENPICC = &OPENPICC_HARDWARE[release];
	
	
    /*	When using the JTAG debugger the hardware is not always initialised to
	the correct default state.  This line just ensures that this does not
	cause all interrupts to be masked at the start. */
    AT91C_BASE_AIC->AIC_EOICR = 0;

    /*	Enable the peripheral clock. */
    AT91C_BASE_PMC->PMC_PCER = 1 << AT91C_ID_PIOA;
    AT91C_BASE_PMC->PMC_PCER = 1 << AT91C_ID_PIOB;    

    /* initialize environment variables */
    env_init();
    if(!env_load())
    {
	env.e.mode=0;
	env.e.reader_id=255;
	env_store();
    }
}

/**********************************************************************/
void vApplicationIdleHook(void)
{
    static char disabled_green = 0;
    //static int i=0;
    //vLedSetGreen(i^=1);
    if(!disabled_green) {
    	//vLedSetGreen(0);
    	disabled_green = 1;
    }
}

/* This task pings the watchdog even when the idle task is not running
 * It should be started with a very high priority and will delay most of the time */
void vMainWatchdogPinger (void *pvParameters)
{
	(void)pvParameters;
    
	while(1) {
		/* Restart watchdog, has been enabled in Cstartup_SAM7.c */
    		AT91F_WDTRestart(AT91C_BASE_WDTC);
    		vTaskDelay(500*portTICK_RATE_MS);
	}
}

void usb_print_flusher (void *pvParameters)
{
	(void)pvParameters;
	while(1) {
		usb_print_flush();
		vTaskDelay(100*portTICK_RATE_MS);
	}
}

/**********************************************************************/
int main (void)
{
    prvSetupHardware ();
    usb_print_init();
    decoder_init();
    performance_init();
    
    pio_irq_init();
    
    vLedInit();
    
    da_init();
    adc_init();
    
    xTaskCreate (usb_print_flusher, (signed portCHAR *) "PRINT-FLUSH", TASK_USB_STACK,
	NULL, TASK_USB_PRIORITY, NULL);
    /*xTaskCreate (iso14443_layer3a_state_machine, (signed portCHAR *) "ISO14443A-3", TASK_ISO_STACK,
	NULL, TASK_ISO_PRIORITY, NULL);*/
    /*xTaskCreate (iso14443_sniffer, (signed portCHAR *) "ISO14443-SNIFF", TASK_ISO_STACK,
	NULL, TASK_ISO_PRIORITY, NULL);*/
    xTaskCreate (iso14443a_pretender, (signed portCHAR *) "ISO14443A-PRETEND", TASK_ISO_STACK,
	NULL, TASK_ISO_PRIORITY, NULL);
    /*xTaskCreate (tc_sniffer, (signed portCHAR *) "RFID-SNIFFER", TASK_ISO_STACK,
		 	NULL, TASK_ISO_PRIORITY, NULL);*/

	    
    xTaskCreate (vUSBCDCTask, (signed portCHAR *) "USB", TASK_USB_STACK,
	NULL, TASK_USB_PRIORITY, NULL);
	
    vCmdInit();
    
    xTaskCreate (vMainWatchdogPinger, (signed portCHAR *) "WDT PINGER", 64,
	NULL, TASK_ISO_PRIORITY -1, NULL);
	
    //vLedSetGreen(1);
    
    /* Remap RAM to addr 0 */
    AT91C_BASE_MC->MC_RCR = AT91C_MC_RCB;    

    vTaskStartScheduler ();
    
    return 0;
}

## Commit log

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2006-07-21 fix usb device enumeration (IRQ based)
    [main.c]
2006-07-21 fix spi
2006-07-22 - add S256 linker script - add USB transmit routines - connect usb OUT endpoint with parser / spi
2006-07-23 fix length of returned usb packet
    [main.c]
2006-07-23 - increase to 320kHz SPI clock rate - enable SPI overflow interrupts
2006-07-23 - reset endpoint in case of CLEAR FEATURE request (data toggle!) - fix endpoint numbering (if we have 0x01, we can't have 0x81) - don't generate interrupts for EP2/EP3 (yet) - correct use of DEBUGPCR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
2006-07-23 - message about not implemented VFIFO stuff - fix length of read fifo packets
    [main.c]
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2006-07-23 - add RC632 Interrupt USB packet generation - use new IRQ priority definitions
2006-07-23 - fix fifo read length - use openpcd defines for endpoints
    [main.c, openpcd.h]
2006-07-25 fixed linker/makefile & updated 'board.h'-concept
    [AT91SAM7.h]
2006-07-25 - add some comments on what this code does - more debugging output - switch LED1(red) according to the result of the transceive operation
2006-07-28 - move all librfid-imported header files into include/librfid/ - import rfid_layer2_iso14443a.c from librfid - fix definition of 14443A ATQA to be __attribute__((packed)); - fix SPI DMA routines (hop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
    [main.c]
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2006-07-30 add definition for STALLSENT bit in UDP CSR register
    [AT91SAM7.h]
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2006-07-30 - use 4.8MHz SPI in case of DMA - fix wait-after-powerup to vendor-specified command reg polling - fix function prototype in case !DEBUG
2006-07-30 - update code to reflect req_ctx changes - use interrupt based UDP send for EP2 - untested implementation to send FIFO read in multiple packets (64byte payload + hdr)
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2006-08-03 - change from PA23 to PA0 - specify duty cycle in percent - fix timing calculations
    [pwm.c]
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2006-08-03 - fix prototype in header - make sure we disable SSC before enabling PWM
    [pwm.c]
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2006-08-08 fixup-commit to last one: main_reqa supports TC, not main_pwm.
    [main_pwm.c]
2006-08-08 add missing prototype
2006-08-08 major rework of carrier division signals: 1) RFID_RESET moved PA29 -> PA5 2) MFIN (PWM0 output) moved PA0 -> PA23 3) PA0 recondfigured as TIOA0 output (CDIV_HELP) 4) PA29 reconfigured as TCLK2 input 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
    [openpcd.h, pwm.c]
2006-08-08 Add SSC rx support to PWM firmware, so we can sample what we output ;)
2006-08-09 - import some more low-level routines from linux kenrel arm port to save memory footprint - make compilation of components only required for debugging conditional
2006-08-16 - make USB IRQ Debug conditional to DEBUG_UDP_IRQ #define - reset internal state of number of packets in transit in case of clear_feature_endpoint
2006-08-16 - introduce ALWAYS_RESPOND #define to determine whether we should always send a blank response even to write commands - fix length calculation in case of FIFO write
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2006-08-20 - main_reqa: add mode to send deterministic ISO14443A frame - rfid_layer2_iso14443a: don't export function that is available via function pointer
2006-08-23 fix ACK_BANK0 case of control transfer (missing ampersand)
2006-08-23 - stop SSC with 'S' - add help message for inc/dec cdiv_idx - add printout for cdiv_idx - declare some constant values as const
2006-08-23 - fix OPENPCD_REG_MAX typo - add USBTEST class
    [openpcd.h]
2006-08-23 - fix size for request contexts to 64 bytes - fix GPIO definitions for olimex board
    [openpcd.h]
2006-08-25 - add unfinished support for DFU (up to now state machine switching works, including change of interrupt handlers, etc)
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2006-09-05 Add DFU support (unfinished, doesn't actually flash yet)
    [openpcd.h]
2006-09-09 we now only have the tc_fdt part of the TC driver in the PICC section
2006-09-09 - we now definitely use PA22 for UDP_PUP, since SAM-BA wants to use PA16, but in inverted fashion. - Move MCLK definition to this header
    [openpcd.h]
2006-09-09 - tons of compile fixes for untested PICC code
    [main_openpicc.c]
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2006-09-10 - add (currently unused) ability to put CPU in idle mode - enable LED2 (red) after startup
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2006-09-10 - Introduce new "BOARD=" make parameter to distinguish between PICC and PCD PIO - Fix PIO assignments to accomodate post-production change in PICC schematics
    [openpcd.h]
2006-09-10 - Add notification in case PLL PIO status changes (serial + LED1)
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2006-09-12 - fix bootloader switch detection
    [main.c, openpcd.h]
2006-09-12 some more debug related options (PLL lock status, button status, ssc start/stop, slave_reset)
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2006-09-13 Completely separate DFU from application program, we now have a real bootloader. DFU occupies 0x00100000 - 0x00100fff in flash, application starts at 0x00101000. DFU also occupies the first couple of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
    In order to produce a samba-flashable image, first build dfu.bin by typing
    'make -f Makefule.dfu', succeeded by 'make TARGET=... DEBUG=... BOARD=...' and then
    concatenating the two files together, e.g. cat dfu.bin main_reqa.bin > flash.bin.
    Actual flashing via DFU is still not operational, but will be implemented next
2006-09-14 add flash size definitions for AT91SAM7S64/32, correct/complete those for S128/S256
    [AT91SAM7.h]
2006-09-20 - Add OpenPICC register definition (and USB command handling) - Add automatic generation of include/compile.h with svn revision and compiletime - Add openpcd_compile_version structure to obtain versi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
2006-09-22 fix completely broken logic of processing pending outbound packets. We now do all the req_ctx state changes from within pcd_handler.c and only expose the refill_ep() functions.
    It's questionable whether we need to keep calling those functions all the time
    either. Once kicked off, the tx completion interrupts of the UDC will refill
    the pipe as long as there is data available.
    So realistically speaking, we'd only need to trigger tx once (and keep
    triggering until no EBUSY or other error is signalled anymore). Some form of
    state machine would be fine for doing this, one that registers a timer with
    the core OS timer (once we have something equivalent to 'struct timer_list'.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
2006-09-22 - we increase the DFU size from 4k to 16k size. This is mainly due to the SAM7S128 and SAM7S256 being restricted to 16k lock region size. If we want to lock the bootloader, it has to be 16k aligned. 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
2006-09-22 - move large rctx definitions to req_ctx.h - add more fine-grained debugging macros in pcd_enumarate.c - resolve race conditions between main-loop ep_refill and irq-triggered ep_refill by adding one 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
    [main.c]
2006-09-22 make sure DFU loader always prints some informational / copyright message upon startup
2006-09-23 - Implement runtime DFU switching and reset-after-update. This means we can now reflash without any buttons or replugging of the device
2006-09-23 - fix return value in case of unknown command
2006-09-27 - increase number of large (2k) contextx to 8 - move req_ctx_find_get into ram, since this is frequently used within interrupt handlers and thus ought to be as fast as possible - correctly initialize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
2006-10-01 - finish implementation of timers based on PIT - add [untested] code for timer-based LED blink codes
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2006-10-01 - add proper system interrupt (shared) demultiplexing code - port debug unit, watchdog timer, periodic interval timer to system_irq.c
2006-10-03 - we have to respond with a STALL to SET_CONFIGURATION - add a comment about this strange fact - some code cleanup - add missing 'break' after end of GET_DESCRIPTOR USB_DT_DEVICE
2006-10-04 - first working tested version if system_irq demux - fix minor issues with PIT timer code - make new led blinkcode implementation work
    [main.c]
2006-10-04 add hardvare version 0.4 data
    [BOTMARKP.GBR, BOTSIDE.GBR, BOTSOLST.GBR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]
2006-10-04 v0.4 of the readers uses a different pin for the USB pullup
2006-10-15 - add svn:ignore property to make 'svn st' output more realistic - remove old copy+paste+edit port of parts of librfid - add ability to directly link librfid.a from mainline librfid - make usb string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
2006-11-28 add new 'main_mifare' firmware to demonstrate in-reader librfid mifare implementation. 'j' and 'k' keys on debug port can be switched to read different sectors.
2006-12-18 - add new DAC driver (instead of poti) for PICC - DFU: put all DEBUG_ defines in "#ifdef DEBUG" enclosure - alter GPIO defines for new OpenPICC v0.4 prototype - add new AT91F_DBGU_Fini() function - t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
    [main_openpicc.c, openpcd.h]
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2006-12-18 add DAC driver that was missed two commits ago
2007-04-10 added several new USB commands: remote reset, API version and read/write volatile flash environment
    [openpcd.h]
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2007-04-10 added blinking green LED to visualize USB inner loop activity - important to verify that OpenPCD is stil lrunning
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2007-11-07 Start working at dfu by copying from main openpcd repository (with modifications), doesn't boot application yet
    [board.h]
2007-11-11 Revert 313 and 315 again, I'm too stupid to get DFU working, focus on the application code first
    [board.h, main.c]
2007-11-11 Fix device name in USB descriptor
2007-11-11 Enhanced flash script with automatic UART detection and automatic flashing on connection Can be left running for longer times and will flash automatically when connecting device in SAM-BA mode
2007-11-11 Add code modules for tc_fdt, tc_cdiv_sync, tc_cdiv, ssc_picc Almost all of these have not been checked yet, I just copied them over and hot-fixed compile time errors F.e. all ssc usb code has been re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
    [board.h, main.c]
2007-11-13 Add PIO IRQ counter (and print it in 'c' command) Make tc_cdiv_sync interrupt working Add 'p' command to print some PIO inputs Add 'z' command to enable/disable tc_cdiv_sync
2007-11-13 Get tc_cdiv working (presumably, need to check on the oscilloscope) Add adc code to read the field strength
2007-11-13 Slight progress, still: enabling tc_fdt crashes the processor after some bits
    [board.h, main.c]
2007-11-14 Rewrite irq handlers according to the new information in http://www.freertos.org/portsam7xlwIP.html: /* Call the handler function. This must be a separate function unless you can guarantee that handl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
2007-11-18 Add (ring-)buffered print functions to enable debug output from IRQ handlers or similar situations
2007-11-19 Add ssc rx start and reboot commands Print version and compile date on help and config commands
2007-11-21 Checking in status quo: Can currently receive and print frames in ssc continuous mode (with new short and incomplete ssc irq handler: FIXME, either switch back to original handler (maybe fixing it if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
    [main.c]
2007-11-21 Commit status quo: Start adding iso 14443 layer 3a code Currently working on fiq for pio data change to reset tc0 via swtrg
    [board.h, main.c]
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2007-11-23 Commit status quo (pending cleanup of the debug and experimental code that I added during the last week) Change freertos code to not mask FIQ, this finally makes the FIQ working (with approx 700ns +/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
2007-11-26 Prepare transmission code Restructure/add some buffer code Reset the watchdog timer (now at 1.5s), add a watchdog pinger thread
    [main.c]
2007-11-27 Print relevant SSC registers Set correct tc_cdiv for sending (FIXME: need to reset before receiving)
2007-11-29 Switch to hardcoded fiq handler implementation directly in the vector table (milosch's idea)
2007-11-29 Fix SSC TX registers (especially the clock source selection), peripheral configuration in ssc_tx_init Implement software (FIQ based) workaround for the problem that TF seemingly cannot be used as a s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
    [board.h]
2007-11-30 Fix power-on logic for the case that the card is already in the field
2007-12-02 Document the current state of the timers (e.g. what laforge did), partly as a tool for myself to aid in debugging
2007-12-02 Add dia file with timer design visualisation I finally understood the CARRIER_DIV_HELP stuff. That's to support a variable phase shift at a fixed duty cycle. (Phase shift isn't used in my current cod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
2007-12-03 * Reduce leaking of TX buffers * Found the problem that when switching between receiving and sending tc_cdiv would most of the time not generate an SSC_CLOCK for approx. 5ms: The issue is that after 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
2007-12-03 Graphical explanation of what should/could happen when TC0 RC is re-set to a lower value than the current TC0 CV. (Also shows the TIOA0 and TIOB0 behaviour)
2007-12-04 Add (#ifdef'ed out) code to measure critical section timing with an LED
2007-12-04 Change tc_cdiv_set_divider. The new code seems to work nearly perfect (jitter is now near 1 sample for the fdt of 1172)
2007-12-05 Revamp SSC buffer handling, should severely reduce buffer leakage Switch SSC IRQ handling from edge triggered to level triggered. Somehow I was losing the ENDTX interrupt otherwise Modified ISO14443 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
2007-12-09 Prevent late frames by spinning in SSC CP0 IRQ till end of short frame reception Fix tc_cdiv_set_divider. again. Reverse the polarity! (of the ssc transmit clock)
2007-12-11 Several modifications to enable spinning until the correct phase is reached in tc_fdt (thereby taking the phase information from tc_fdt, resetting the phase in tc_cdiv) Still too much jitter (some bu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
2007-12-12 Add new miller decoder (not working yet) Vastly improve timing through CPU cycle counting. Jitter is now like 40ns (the SSC_DATA edge detection fuzziness) in 2 main clusters 4 CPU cycles (83ns) apart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
2007-12-14 Sanitize and clarify the len handling in rx buffers. Fix miller decoder
    [main.c]
2007-12-15 Fix consistency check Fix miller decoder for the case of a buffer containing only zeroes
2007-12-15 Prepare generic ISO 14443A reception mode (no short/standard distinction), prerequisite for proper frame handling and anticol, doesn't work yet
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2008-02-09 Commit a first version of an iso 14443 layer 2 and a passive sniffer. Works for short frames, and sometimes even for long frames. Pending some major cleanup
    [main.c]
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2008-03-03 Implement transmission Implement a 'pretender' for PoC: Since Rx is not working properly we'll just pretend to have received something based on the approximate length. Clarify length calculations in 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
    [main.c]
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2008-03-09 Fix sending Add Tx abort and SSC reset functionalities There is a bug workaround for a peculiarity in the SSC Tx: When it is set to START CONTINOUS while a transmission is in progress (started by STA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
2008-03-10 Further optimisation on the differential miller decoder, is now down to 1750 MCK/2 cycles for the short frame
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2008-03-15 Fix the clock gating for the new layer 2 code Only perform the switch to continous when necessary since it has serious side effects in the current hardware (we really need TF ored into the clock gati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
2008-03-18 Remove performance print, it's blocking the IRQ too long which in turn will make the SSC TXSYN IRQ arrive late, which will make the SSC not switch to CONTINUOUS in time which will truncate all frames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
2008-03-18 Print error code in case of error
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2010-11-13 On the Olimex board, the buttons are low-active
    Thus, we need to invert our check during the dfu / main dual boot
    decision
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2010-11-18 ausb: fix interrupt URB callback
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2010-11-21 AT91SAM7.h: Fix computation of AT91C_IFLASH_LOCK_REGION_SIZE
    [AT91SAM7.h]
2011-01-31 typo: Fix typo, transform reqyests to requests.
    [main_openpicc.c, main_pwm.c, main_simtrace.c]
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2011-06-21 simtrace: switch VCC_SIM into output mode, as we use it to supply Vcc
    This is just a temp rework in the 1st generation prototype, as the bus
    switch has too high resistance for passing throuhg Vcc from the phone
    to the SIM.
    [main_simtrace.c]
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2011-07-29 sam7dfu: make sure we can use USB reset to get from DFU -> APP
    When we went through a Download -> Manifest cycle, we can switch
    back to dfuIDLE. However, we need to memorize that manifest had
    already happened and thus should treat a host-initiated bus reset
    as trigger to switch back into application mode.
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2011-08-15 DBGU: Print Reset controller Status Register on boot
    This helps us to discover _why_ the CPU has been rebooted.
2011-08-15 simtrace UART: set INACK flag to make sure we ignore any parity error
    As a SIM card tracer, we want to remain completely passive and thus not
    signal back parity errors with the ISO 7816 NACK.
    The UART INACK flag does exactly that...
2011-08-15 SIMTRACE UART: Reset error status on error related IRQ
    This prevents an IRQ-flood after a parity or overrun error, which
    in turn would cause a watchdog reset.
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2011-10-21 Fix fi/di calculation for certain mobiles like GT-S770 or HTC Raphael
    There were some mistakes while copying the tables from ISO 7816-3,
    and also a quite old version of 7816-3 was used.
2011-11-10 dfu: The i variable to disable interrupts shadows the outer index
    In case ram_app_entry() returns do not reset i to 32, otherwise we
    will never reset the watchdog.
    src/dfu/dfu.c:1077:7: warning: declaration of ‘i’ shadows a previous local [-Wshadow]
    src/dfu/dfu.c:1068:6: warning: shadowed declaration is here [-Wshadow]
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2011-12-14 usb: Do not send ZLP when we have filled the window
    Only send the ZLP if we send less data than was required/asked for
    by the host and it is a multiple of the bMaxPacketSize0 (which is
    hardcoded to 8 right now).
    This is completing the change done in fe88b83e80df8be0351ff38ee6 to
    fix SIMtrace attached to OSX and not regress on windows.
    Introduce another parameter to udp_ep0_send_data to specify the window
    size (wLength) or if not available the default from USB 2.0 specification.
2011-12-18 Make sure we don't forward power _and_ supply SIM power at the same time
    The FPF2005 has no reverse voltage blocker, this is why the 3.3V from
    the LDO flows back into VCC_PHONE. It even damages the chip (so says the
    datasheet) I corrected the double power source problem by disabling the
    LDO (see patch), but still 1.8V does not work and 3.0-3.3V is used. I
    have to look for other reasons.
    [main_simtrace.c, simtrace.h]
2012-01-25 simtrace: 7816 UART: Add missing entry in Di table
    Add missing entry in Fi_table. It's apparently used as '64' in some
    reader and 'unsupported' in some other. For simtrace I guess we should
    consider it 64.
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2012-03-22 simtrace: implement SIM power switching API
    there is now a high-level command by which we can swithc the VCC
    supply of the SIM cards.
    For some reason, the _PASS variant (passing through the voltage from the
    phone) doesn't seem to work reliably. It might be that we are draining
    reverse current throught the LDO once we supply SIM power that way.
    [main_simtrace.c, simtrace.h]
2012-03-22 simtrace: introduce statistics
    the statistics count various events like overruns, parity errors,
    missing rctx and can dump those stats via USB as well as on the serial
    console.
    [main_simtrace.c]
2012-04-08 eabi: Remove EABI functions to fix building with EABI toolchains
    These symbols are not referenced on an arm-elf gcc 4.7, they are
    used when building with an arm-eabi gcc 4.7 and then cause linking
    issues. The linking to libgcc can not be omitted as the irq code is
    using ffs. Remove the EABI symbols. The alternative would be to
    declare the EABI as weak inside the lib1funcs.
    Link error:
    multiple definition of `__udivsi3'
    multiple definition of `__aeabi_uidiv'
    Exported symbols:
    nm lib/lib1funcs.o
    00000000 t Ldiv0
    00000010 T __div0
2014-11-11 pcd_enumerate: Avoid disabling interrupt during endpoint refill
    The old implementation has a big local_irq_save() / restore() around the
    endpoint re-fill routine. This disables interrupts for a long time,
    psossibly causing lost interrupts.
    The new implementation works around this by disabling the USB (UDP)
    interrupt only, rather than disabling all interrupts on the system.
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2014-11-11 Ensure to transmit current req_ctx on RESET/VCC events
    When any of the following events occur:
    * VCC_PHONE off
    * nRST
    * RST
    we tranmsit the current req_ctx, if there is data pending.
    This ensures that for any successive data, the ATR flag in the next
    req_ctx containing the data, not in the previous req_ctx. It also
    ensures that the ATR is aligned at 0 offset in the new req_ctx, which is
    an assumption the host software makes but the previous code didn't
    ensure.
    Furthermore, we introduce a periodic flushing of any pending but
    incomplete req_ctx.
    [main_simtrace.c]
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2014-11-11 iso_uart: Print more errors, not just overruns
    [main_simtrace.c]
2014-11-11 Don't split req_ctx with ATR payload
    The codnition for flushing a req_ctx on UART idle is fixed to flush only
    if
    1) There has been no new data since last check, and
    2) There are no req_ctx currently pending to be transmitted to USB, and
    3) We did NOT just got a reset and waiting for ATR
    I saw an ATR split in two different req_ctx prior, presumably flush
    decided to send req_ctx after ATR but got a new character just before
    sent). If we did get a RESET, let original logic decide to send the
    req_ctx -- presumably when ATR data is fully received.
2014-11-11 Retrieve + print previous PC from stack to debug wdog/spurious IRQ
    Retrive previous PC from the stack before entering specific interrupt
    handler routines. Allow user to trace where interrupt occured: e.g.
    WatchDog and Spurious interrupt
    Prior to this change, spurious interrupt would occur so much (observed
    via gdb/remote debug) so it appears that the board stalled. Once a
    custom spurious interrupt installed, the code continues after the
    interrupt instead of re-entering the interrupt.
    [main_simtrace.c]
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

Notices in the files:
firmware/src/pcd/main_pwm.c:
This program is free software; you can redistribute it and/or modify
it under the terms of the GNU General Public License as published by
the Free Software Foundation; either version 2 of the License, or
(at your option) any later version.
